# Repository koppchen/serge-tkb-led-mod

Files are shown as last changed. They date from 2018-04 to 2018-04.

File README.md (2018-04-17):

# Serge TKB LED Mod

Small PCB designed to add row indicator LEDs to the Serge TKB (Touch Activated Keyboard Sequencer).  This was designed for The Human Comparator TKB version, which was based on the original Serge TKB schematics.

This repo contains the EAGLE board and schematic files, along with the LTSpice schematic for circuit simulation.

## LED mod PCB 

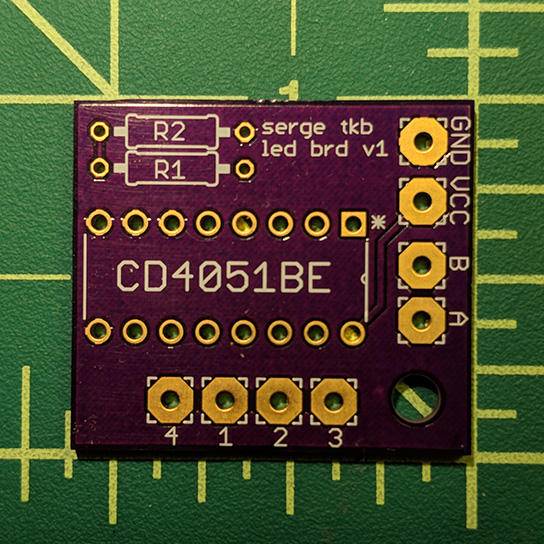
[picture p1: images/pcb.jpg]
PCB


The LED Mod PCB is small enough to be mounted on the top right corner of the main PCB.
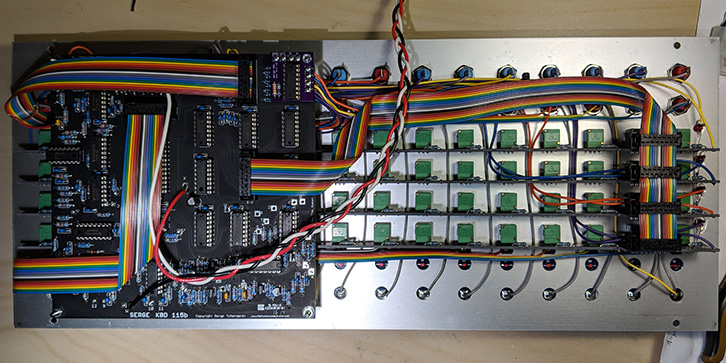
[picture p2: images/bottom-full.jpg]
Bottom full


Pads labeled **GND**, **VCC**, **A**, & **B** are wired to the bottom of CD4520BE on the main PCB.  Pads labeled **1**, **2**, **3**, & **4** are wired to the LEDs of sequencer rows A (1), B (2), C (3), and D (4).
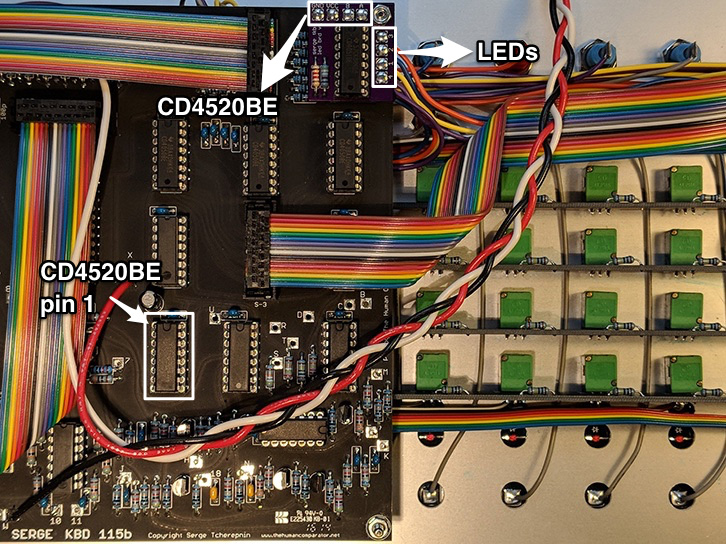
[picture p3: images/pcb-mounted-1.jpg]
PCB mounted 1


Wiring the CD4520BE pins to the LED mod PCB.
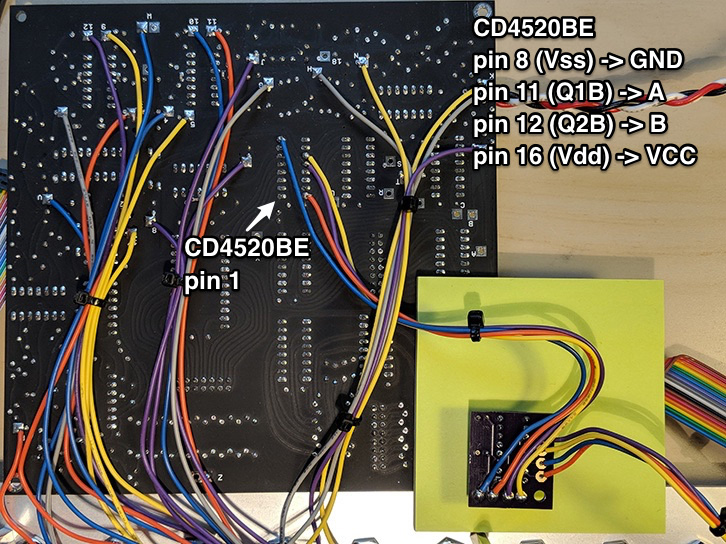
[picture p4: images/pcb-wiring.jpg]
PCB wiring


### Mounted mod PCB

Two nuts will give enough space between the main PCB and mod PCB for the wires.
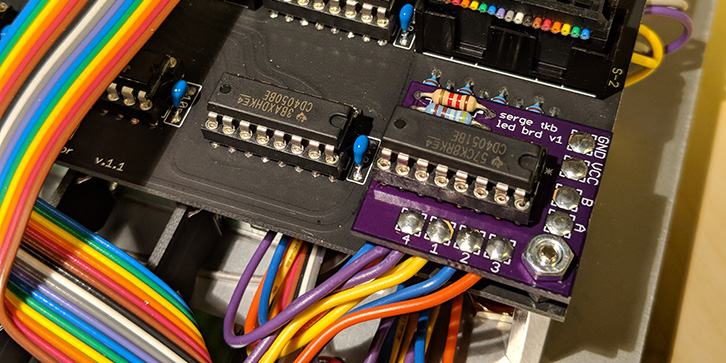
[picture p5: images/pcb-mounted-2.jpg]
PCB mounted 2


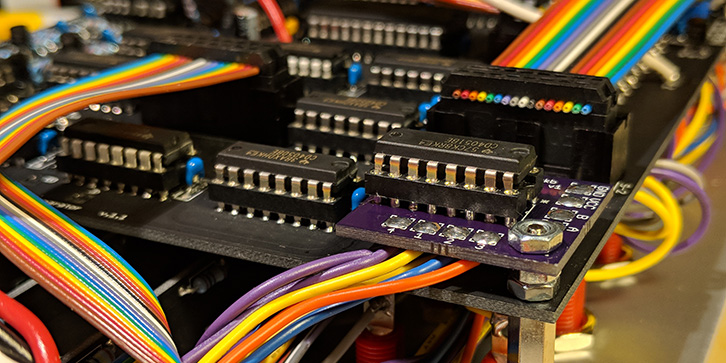
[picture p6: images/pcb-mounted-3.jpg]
PCB mounted 3


### LED wiring

LED anodes are wired to the mod PCB pads **1**-**4**.  LED cathodes are wired to ground.
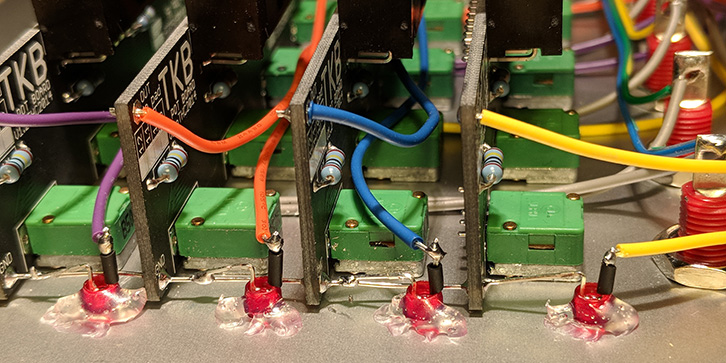
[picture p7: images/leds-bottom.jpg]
LEDs bottom


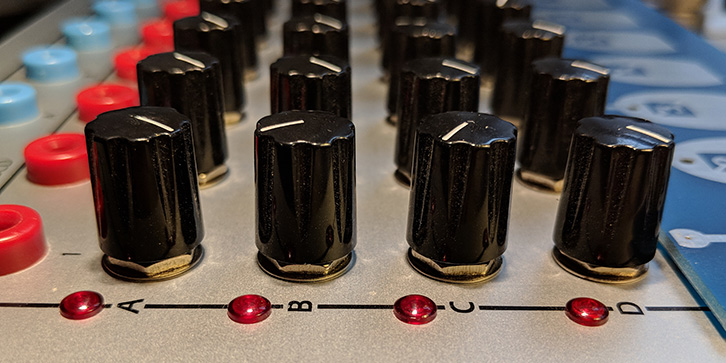
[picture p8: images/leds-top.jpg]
LEDs top


## BOM

| Value | QTY | Description | Mouser Part # |
|:---|:---:|:---|:---|
| CD4051BE | 1 | CMOS Single 8-Channel Analog Multiplexer/Demultiplexer with Logic-Level Conversion | [595-CD4051BE][cd4051] |
| R1 | 1 | 4.99k Resistor |  |
| R2 | 1 | 1.2k Resistor |  |
|  | 4 | Standard LEDs - 3mm Red 25mcd 640nm 40 deg Diffused | [604-WP710A10LSRD][red-leds] |
|  | 4 | LED Lenses Red Fresnel 3mm Lens  | [593-1700R][red-led-lenes] |

[cd4051]: https://www.mouser.com/ProductDetail/595-CD4051BE
[red-leds]: https://www.mouser.com/ProductDetail/604-WP710A10LSRD
[red-led-lenes]: https://www.mouser.com/ProductDetail/593-1700R

## Resources

Serge TKB Schematics:  
<http://machines.hyperreal.org/manufacturers/Serge/schematics/>

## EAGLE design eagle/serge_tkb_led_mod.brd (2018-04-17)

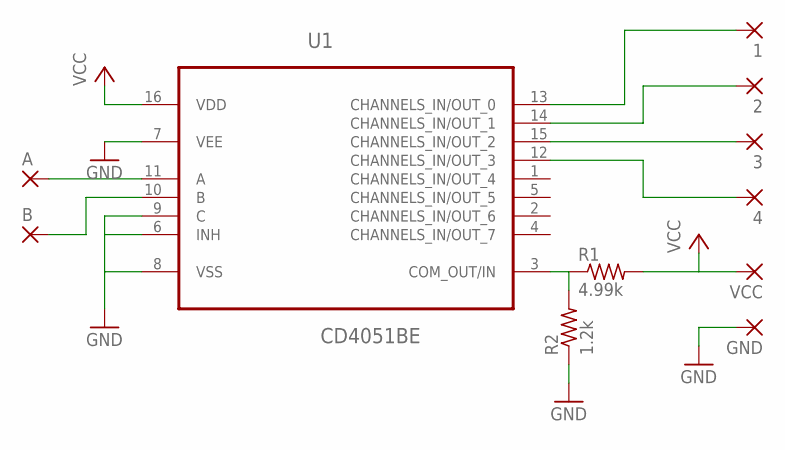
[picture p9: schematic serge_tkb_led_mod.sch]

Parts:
1, 2, 3, 4: 3,17/1,3
A: 3,17/1,3
B: 3,17/1,3
GND: 3,17/1,3
R1: 4.99k; 0207/10
R2: 1.2k; 0207/10
U1: CD4051BE; DIP254P762X508-16
VCC: 3,17/1,3

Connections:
A: A.1, U1.11 (A)
GND: GND.1, R2.1, U1.6 (INH), U1.7 (VEE), U1.8 (VSS), U1.9 (C)
unnamed: R1.1, R2.2, U1.3 (COM_OUT/IN)
unnamed: 1.1, U1.13 (CHANNELS_IN/OUT_0)
unnamed: 2.1, U1.14 (CHANNELS_IN/OUT_1)
unnamed: 3.1, U1.15 (CHANNELS_IN/OUT_2)
unnamed: 4.1, U1.12 (CHANNELS_IN/OUT_3)
unnamed: B.1, U1.10 (B)
VCC: R1.2, U1.16 (VDD), VCC.1

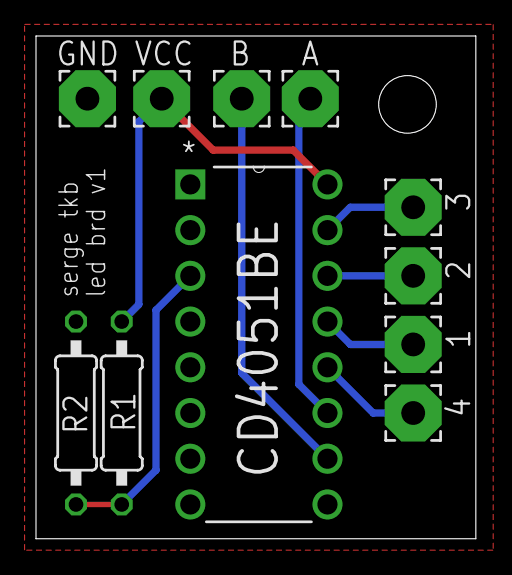
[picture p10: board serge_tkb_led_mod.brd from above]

Board: 2 copper layers, 24.4 x 27.9 mm, 11 parts (0 on the bottom side), 9 nets.
